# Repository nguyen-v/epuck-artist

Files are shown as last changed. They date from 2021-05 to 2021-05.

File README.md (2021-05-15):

# epuck-artist


An edge processing, 4-color equipped wall plotter. 

Embedded Systems and Robotics semester project at [EPFL](https://www.epfl.ch/) using the e-puck 2 robot from [GCtronic](https://www.gctronic.com/).

## Features
- Reproduction of any subject (100 x 90) in 4 different colors (camera, stepper motor)
- Semi-automatic calibration (TOF sensor, stepper motor)
- Interactive starting position configuration (IR sensors, stepper motor)
## Requirements
### Python 3.x
#### External libraries
  - serial
  - PIL
  - numpy

### VSCode with PlatformIO IDE
#### Libraries
  - NeoSWSerial
  - ServoTimer2
  - Stepper

### Eclipse IDE
#### Libraries
  - [e-puck2_main_processor](https://github.com/e-puck2/e-puck2_main-processor) ([wiki](https://www.gctronic.com/doc/index.php?title=e-puck2_robot_side_development))

### Hardware
| Peripheral | Model |
|---|---|
| Robot | [e-puck2 (GCtronic)](https://www.gctronic.com/e-puck2.php) |
| Board | [Arduino Nano ATMega328](https://store.arduino.cc/arduino-nano) | 
| Bluetooth module | [Velleman HC-05](https://www.velleman.eu/products/view/?id=435518) | 
| Servo motor | [ST55MG](https://amewi.com/AMX-Racing-Micro-Digital-Servo-ST55MG) |
| Stepper motor and driver | [Gear Stepper Motor Driver Pack](https://www.seeedstudio.com/Gear-Stepper-Motor-Driver-Pack-p-3200.html) |

## Demos:
### Live demo
<a href="http://www.youtube.com/watch?feature=player_embedded&v=znKsJ0n5lfQ
" target="_blank">IMAGE ALT TEXT HERE</a>

### Timelapses
#### Colorful concentric circles
<a href="http://www.youtube.com/watch?feature=player_embedded&v=ZIJO9M60r-s
" target="_blank">IMAGE ALT TEXT HERE</a>

#### Cubes
<a href="http://www.youtube.com/watch?feature=player_embedded&v=i3Xt1w0KOP0
" target="_blank">IMAGE ALT TEXT HERE</a>

#### GCtronic logo
<a href="http://www.youtube.com/watch?feature=player_embedded&v=iaR-Tps1SmQ
" target="_blank">IMAGE ALT TEXT HERE</a>

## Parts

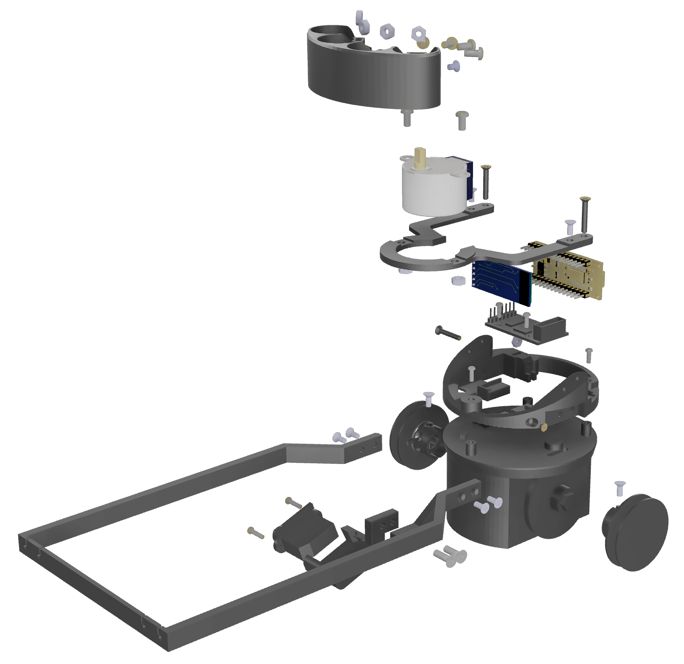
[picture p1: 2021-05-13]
3d_printed_parts/e-puck_exploded_view.png

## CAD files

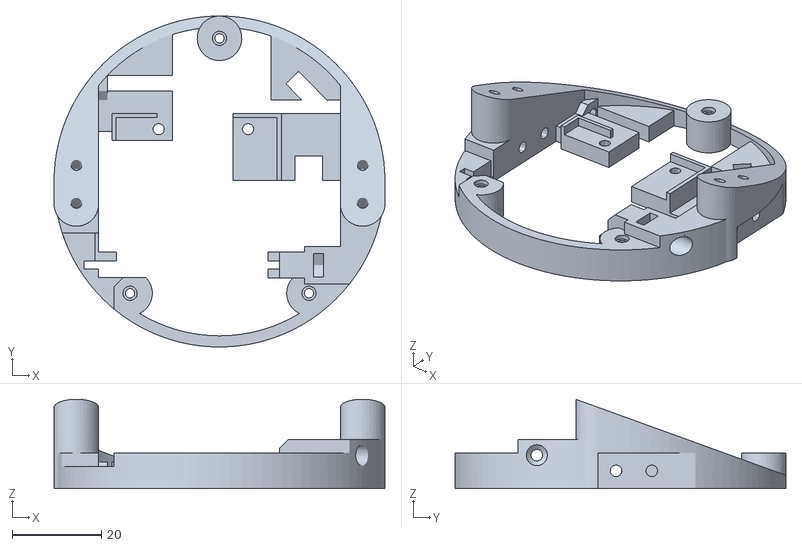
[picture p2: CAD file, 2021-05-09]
3d_printed_parts/MAIN_SUPPORT.stl
74.0 x 74.0 x 20.0

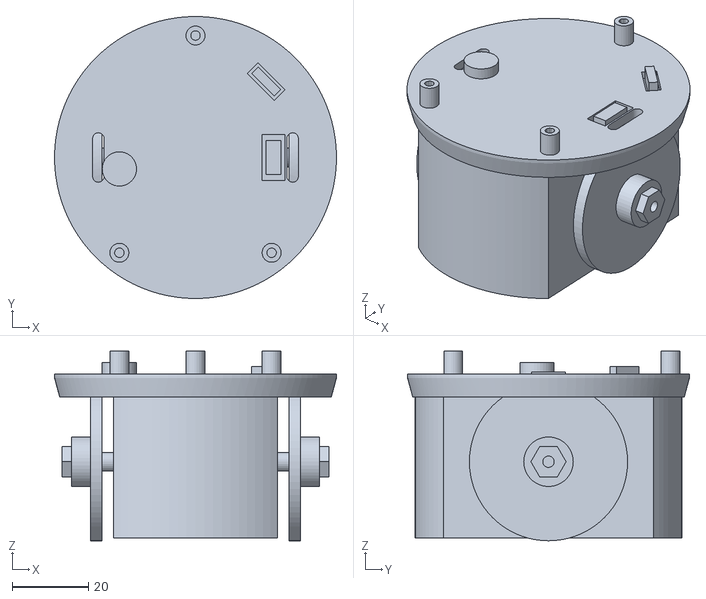
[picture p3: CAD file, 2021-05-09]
misc/EPUCK-2.stl
74.0 x 74.0 x 49.8

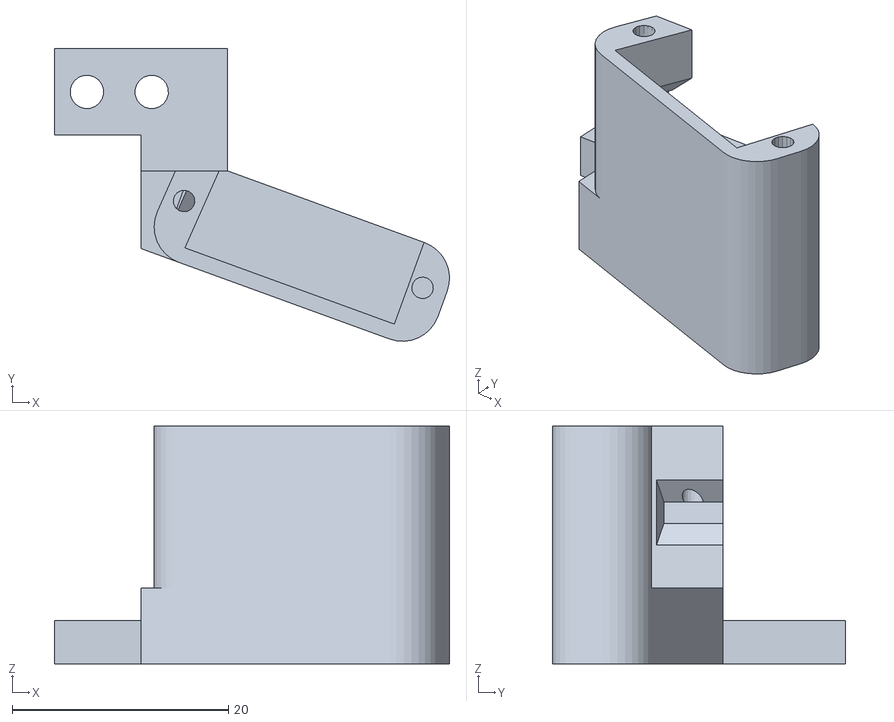
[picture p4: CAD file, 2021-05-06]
3d_printed_parts/SERVO_HOLDER.stl
36.6 x 27.1 x 22.0

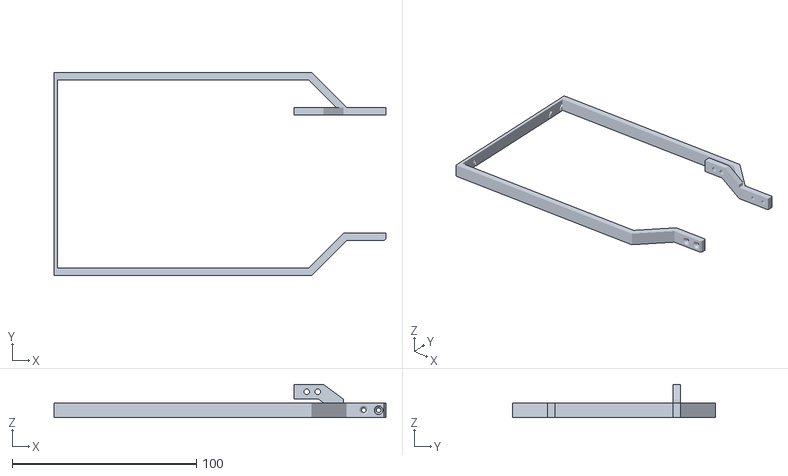
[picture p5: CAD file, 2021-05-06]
3d_printed_parts/THREAD_ALIGNER.stl
180.0 x 110.0 x 18.0

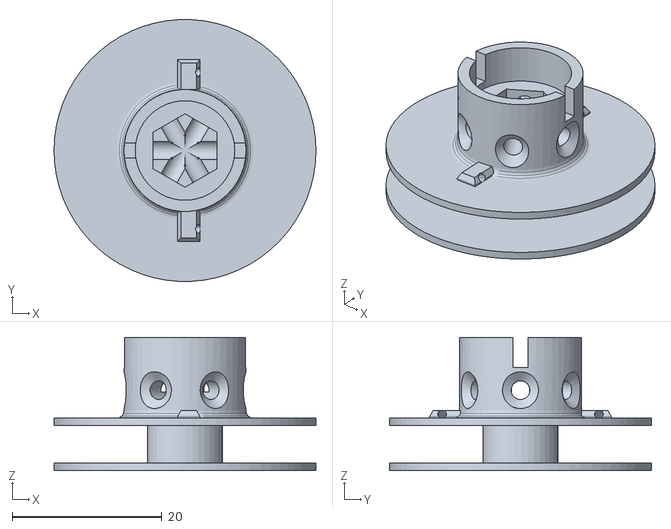
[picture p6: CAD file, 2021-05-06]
3d_printed_parts/WHEEL_PULLEY_D10.stl
35.0 x 35.0 x 17.8

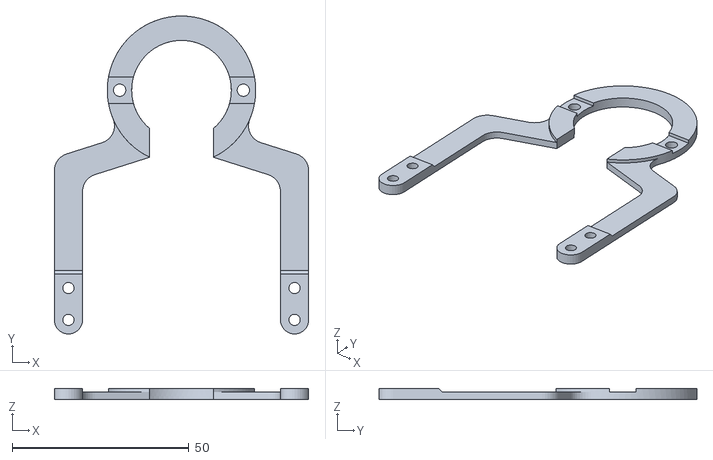
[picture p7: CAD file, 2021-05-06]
3d_printed_parts/STEPPER_SUPPORT.stl
72.0 x 90.0 x 3.00

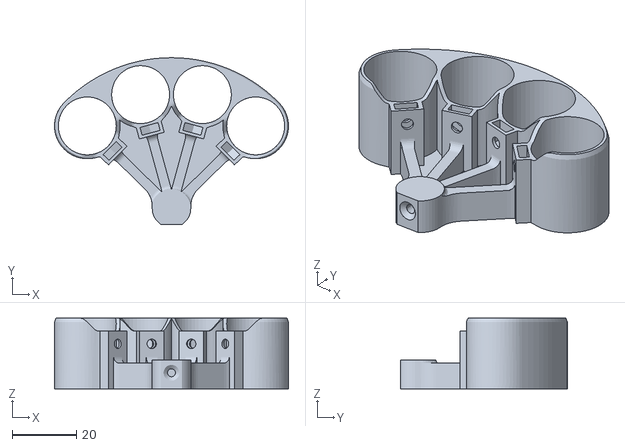
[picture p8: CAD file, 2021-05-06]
3d_printed_parts/PEN_CARRIAGE.stl
72.7 x 51.8 x 22.0

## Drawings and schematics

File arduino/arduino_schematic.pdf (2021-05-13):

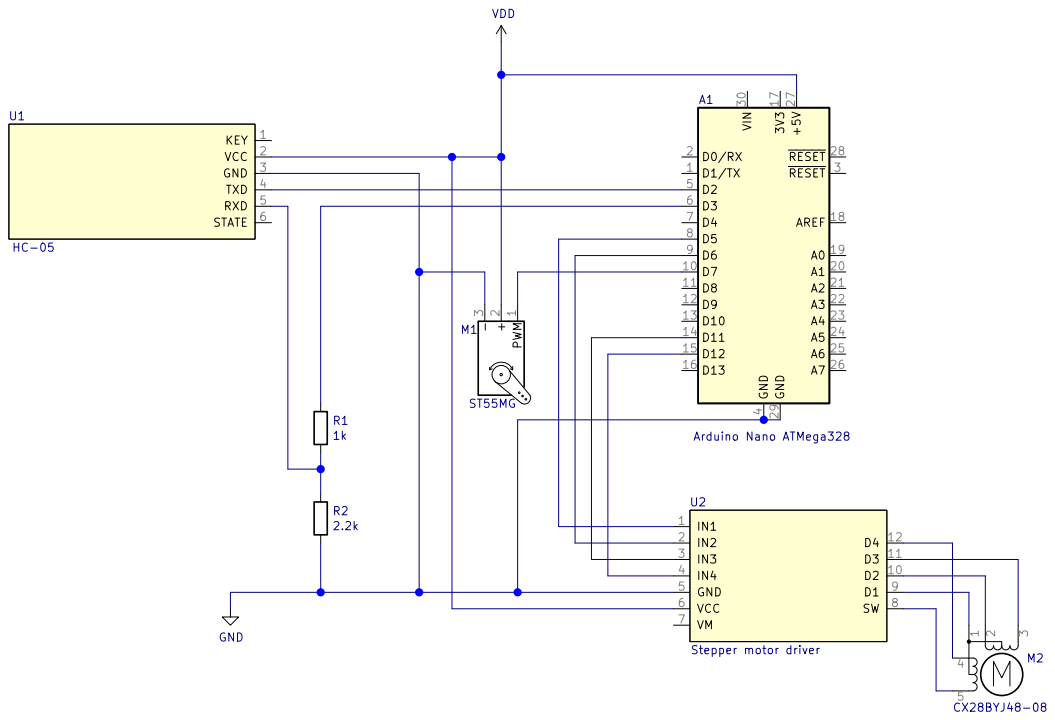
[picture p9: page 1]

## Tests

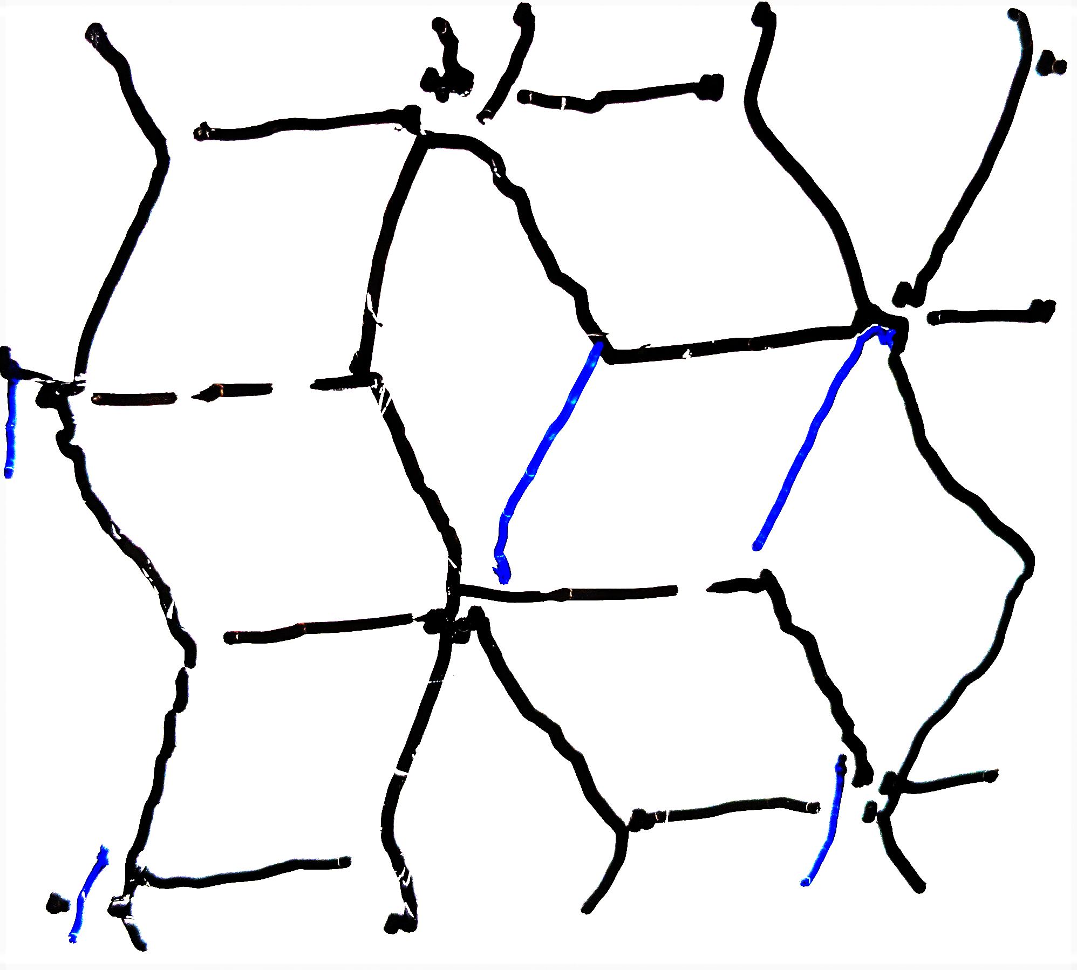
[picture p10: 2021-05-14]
misc/examples/cubes/result_cubes.png

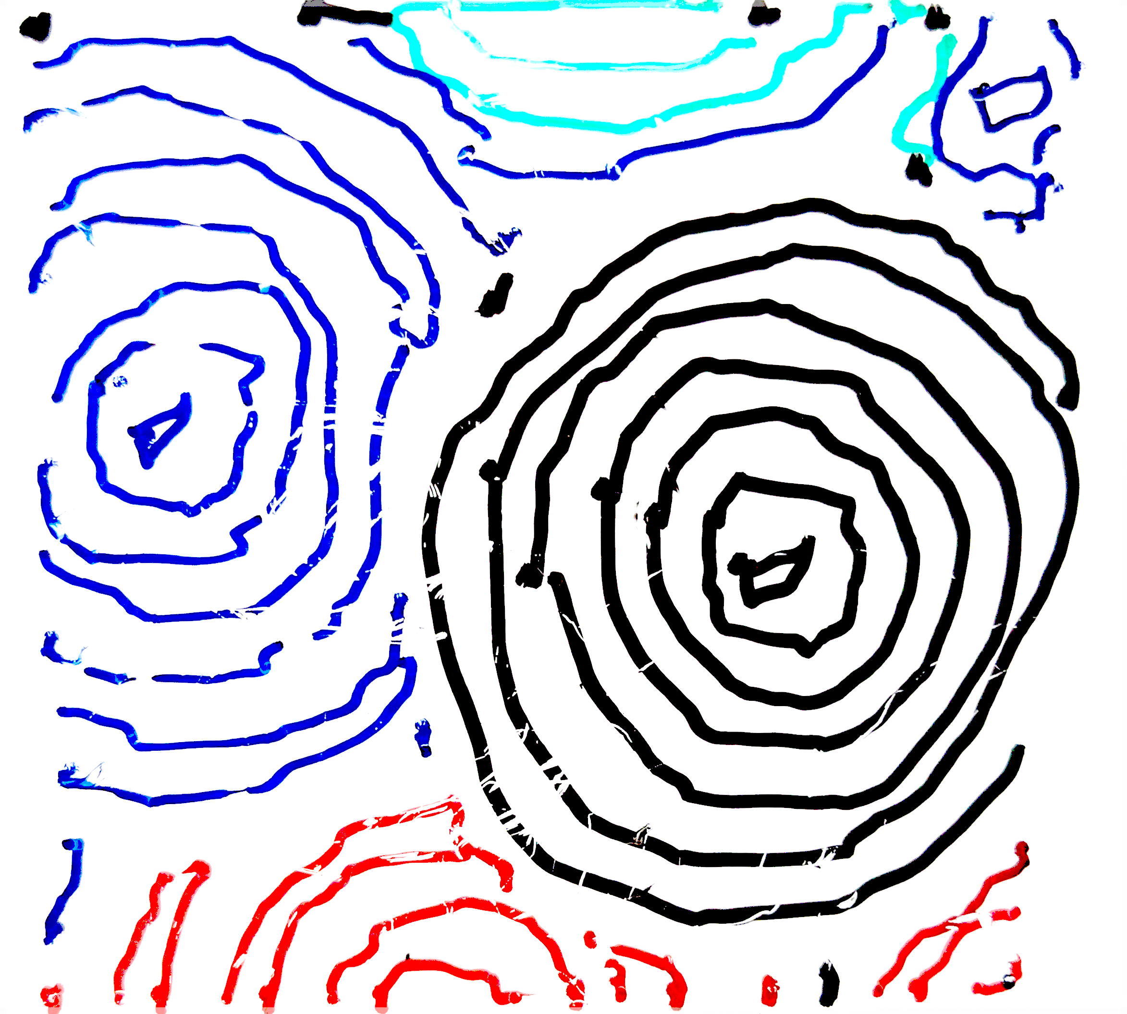
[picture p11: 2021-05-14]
misc/examples/circles/result_circles.png

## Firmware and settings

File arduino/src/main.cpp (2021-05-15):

/**
 * @file    main.cpp
 * @brief   Handles BT communication, servomotor and stepper motor of Arduino.
 *          Very simple program to move the stepper motor to the correct 
 *          position and lift the pens if necessary.
 * 
 * @note    SoftwareSerial.h and Servo.h conflict with each other (timer)
 *          The only compatible libraries tested are NeoSWSerial paired
 *          with ServoTimer2
 */

// Hardware                                                                  

// Board:                 Arduino Nano ATmega328
// Bluetooth module:      Whadda Funkmodul HC-05 Bluetooth
// Servomotor:            Amewi Servo Digital Micro ST55MG 5.5g 
// Stepper motor/driver:  Gear Stepper Motor Driver Pack - Seeed Studio

#include <Arduino.h>

// Libraries
#include <NeoSWSerial.h>
#include <ServoTimer2.h>
#include <Stepper.h>

/*===========================================================================*/
/* Module constants.                                                         */
/*===========================================================================*/

// Messages
#define CONFIMATION_MSG           "Ready"

// Intervals
#define SERVO_STEPPER_INTERVAL    500 // ms

// HC-05 bluetooth module
#define BT_SERIAL_PIN_1           2
#define BT_SERIAL_PIN_2           3
#define BT_BAUD_RATE              9600

// Serial
#define SERIAL_BAUD_RATE          9600

// Servo
#define PIN_SERVO                 10
#define DELTA_PULSE               350

// Stepper
#define PIN_STEPPER_1             5
#define PIN_STEPPER_2             11
#define PIN_STEPPER_3             6
#define PIN_STEPPER_4             12
#define STEPPER_SPEED             5
#define STEPS_PER_REV             2048

// 4 pens are placed on a bit more of a quarter of the full revolution
#define STEPPER_MAX_VALUE         690

// because of weight distribution, epuck is tilted depending on the color chosen
// an offset is added to compensate. The positions are from right to left.
#define STEPPER_OFFSET            30
#define STEPPER_POSITION_0        (0 + STEPPER_OFFSET)
#define STEPPER_POSITION_1        (STEPPER_MAX_VALUE/4 + STEPPER_OFFSET/2)
#define STEPPER_POSITION_2        (STEPPER_MAX_VALUE*2/4 - STEPPER_OFFSET/2)
#define STEPPER_POSITION_3        (STEPPER_MAX_VALUE*3/4 - STEPPER_OFFSET)

#define DEFAULT_POSITION          STEPPER_POSITION_0

/*===========================================================================*/
/* Module data structures and types.                                         */
/*===========================================================================*/
enum Color {white, black, red, green, blue};

/*===========================================================================*/
/* Module local variables.                                                   */
/*===========================================================================*/

static NeoSWSerial BTserial(BT_SERIAL_PIN_1, BT_SERIAL_PIN_2);
static ServoTimer2 servo;
static Stepper stepper = Stepper(STEPS_PER_REV, PIN_STEPPER_1, PIN_STEPPER_2, 
                                 PIN_STEPPER_3, PIN_STEPPER_4);
static int16_t stepper_position = DEFAULT_POSITION;


/*===========================================================================*/
/* Module local functions.                                                   */
/*===========================================================================*/

/**
 * @brief             moves stepper motor and servo motor to change colors
 * @param[in]   col   a valid color (enum Color)
 * @return            none
 */
static void change_color(Color col)
{
	// lift servo
	servo.write(DEFAULT_PULSE_WIDTH+DELTA_PULSE);
	delay(SERVO_STEPPER_INTERVAL);
	int16_t goal_step = 0;
	switch (col) {
		case white:
			return; // if white is requested, just lift the pens
			break;
		case black:
			goal_step = STEPPER_POSITION_0;
			break;
		case red:
			goal_step = STEPPER_POSITION_1;
			break;
		case green:
			goal_step = STEPPER_POSITION_2;
			break;
		case blue:
			goal_step = STEPPER_POSITION_3;
			break;
	}

	int16_t delta_step = goal_step - stepper_position;
	stepper.step(delta_step);
	delay(SERVO_STEPPER_INTERVAL);
	stepper_position = goal_step;
	// lower servo
	servo.write(DEFAULT_PULSE_WIDTH);
}

/**
 * @brief             resets motors to their standby state.
 * @return            none
 */
static void reset_motors()
{
	servo.write(DEFAULT_PULSE_WIDTH+DELTA_PULSE);
	delay(SERVO_STEPPER_INTERVAL);
	int16_t goal_step = DEFAULT_POSITION;
	int16_t delta_step = goal_step - stepper_position;
	stepper.step(delta_step);
	stepper_position = goal_step;
}

/*===========================================================================*/
/* Module functions.                                                         */
/*===========================================================================*/

void setup() 
{
	servo.attach(PIN_SERVO);
	stepper.setSpeed(STEPPER_SPEED);

	Serial.begin(SERIAL_BAUD_RATE);
	BTserial.begin(BT_BAUD_RATE);

	delay(SERVO_STEPPER_INTERVAL);
	servo.write(DEFAULT_PULSE_WIDTH+DELTA_PULSE);
}

void loop() 
{
	if (BTserial.available()) {
		char cmd = BTserial.read();
		switch (cmd) {
			case 'W':
				change_color(white);
				break;
			case 'D': // dark
				change_color(black);
				break;
			case 'R':
				change_color(red);
				break;
			case 'G':
				change_color(green);
				break;
			case 'B':
				change_color(blue);
				break;
			case 'X':
				reset_motors();
				break;
		}
	BTserial.println(CONFIMATION_MSG);
	}
}

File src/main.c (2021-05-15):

/**
 * @file    main.c
 * @brief   Main file. Handles interactions between modules.
 */

// ChibiOS headers

#include "ch.h"
#include "hal.h"
#include "memory_protection.h"
#include "chprintf.h"
#include <usbcfg.h>
#include <motors.h>

// e-puck 2 main processor headers

#include <camera/po8030.h>
#include "camera/dcmi_camera.h"


// Module headers

#include <main.h>
#include <mod_sensors.h>
#include <mod_draw.h>
#include <mod_communication.h>
#include <mod_img_processing.h>
#include <mod_calibration.h>
#include <mod_data.h>
#include <mod_state.h>

/*===========================================================================*/
/* Module local functions.                                                   */
/*===========================================================================*/

/**
 * @brief             Initalizes all modules.
 */
static void init_all(void)
{
	halInit();
	chSysInit();
	mpu_init();
//	usb_start(); // uncomment if using chprintf on SDU1
	dcmi_start();
	po8030_start();
	com_serial_start();
	mod_img_processing_init();
	motors_init();
	sensors_init();
}

/*===========================================================================*/
/* Main function.                                                   		 */
/*===========================================================================*/


int main(void)
{
	init_all();
	draw_set_init_length(DEFAULT_HEIGHT_CM);
	create_thd_process_cmd();
	while(1) {
		chThdSleepMilliseconds(100);
    }
}

#define STACK_CHK_GUARD 0xe2dee396
uintptr_t __stack_chk_guard = STACK_CHK_GUARD;

void __stack_chk_fail(void)
{
    chSysHalt("Stack smashing detected");
}

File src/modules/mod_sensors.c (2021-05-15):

/**
 * @file    mod_sensors.c
 * @brief   Module for managing sensors
 */

// C standard header files

#include <stdio.h>
#include <stdlib.h>
#include <math.h>

// ChibiOS headers

#include "ch.h"
#include "hal.h"
#include "memory_protection.h"
#include "msgbus/messagebus.h"
#include "chprintf.h"
#include <usbcfg.h>

// e-puck 2 main processor headers

#include "sensors/VL53L0X/VL53L0X.h"
#include "sensors/proximity.h"

// Module headers

#include <mod_sensors.h>
#include <mod_communication.h>
#include <mod_calibration.h>
#include <mod_data.h>
#include <mod_state.h>

/*===========================================================================*/
/* Module constants.                                                         */
/*===========================================================================*/

#define BLINK_PERIOD       200
#define BLINK_MAX_COUNT    3
#define TOF_PERIOD         100

#define OBSERVED_NOISE_COVARIANCE 6.5f

/*===========================================================================*/
/* Bus related declarations.                                                 */
/*===========================================================================*/

messagebus_t bus;
MUTEX_DECL(bus_lock);
CONDVAR_DECL(bus_condvar);

/*===========================================================================*/
/* Module local variables.                                                   */
/*===========================================================================*/

static uint16_t dist_mm_kalman = 0;

/*===========================================================================*/
/* Module thread pointers.                                                   */
/*===========================================================================*/

static thread_t* ptr_tof_kalman;

/*===========================================================================*/
/* Module local functions.                                                   */
/*===========================================================================*/


/**
 * @brief               1D Kalman filter
 *
 * @return              filtered value
 * @note                Kalman filter is defined in VL53L0X.c because we want
 *                      it to be ready (i.e. running) alongside the thread
 *                      defined in the same file (because values need to be
 *                      stable when accessed).
 *                      sources: https://www.youtube.com/watch?v=ruB917YmtgE
 *                               https://en.wikipedia.org/wiki/Kalman_filter
 */
static uint16_t kalman1d(uint16_t U)
{
	static const float R = OBSERVED_NOISE_COVARIANCE;
	static const float H = 1.00;       // observation model
	static float Q = 1.0;              // initial estimated covariance
	static float P = 0;                // initial error covariance
	static uint16_t U_hat = 0;         // initial predicted state
	static float K = 0;

	K = P*H/(H*P*H+R);                 // calculate Kalman gain
	U_hat = U_hat + K*(U-H*U_hat);     // updated state estimate
	P = (1-K*H)*P +Q;                  // updated estimate covariance
	return U_hat;
}



/*===========================================================================*/
/* Module threads.                                                           */
/*===========================================================================*/

/**
 * @brief   Thread for applying Kalman filter to TOF measurements.
 */
static THD_WORKING_AREA(wa_tof_kalman, 256);
static THD_FUNCTION(thd_tof_kalman, arg)
{
	chRegSetThreadName(__FUNCTION__);
	(void)arg;

	while (1) {
		dist_mm_kalman = kalman1d(VL53L0X_get_dist_mm());
//		chprintf((BaseSequentialStream *)&SDU1, "dist %d", dist_mm_kalman);
		chThdSleepMilliseconds(TOF_PERIOD);
	}
}

/**
 * @brief            Create TOF measurement thread with Kalman filter
 * @return           none
 */
static void tof_kalman_create_thd(void)
{
	ptr_tof_kalman = chThdCreateStatic(wa_tof_kalman, sizeof(wa_tof_kalman),
	                                   NORMALPRIO, thd_tof_kalman, NULL);
}

/*===========================================================================*/
/* Module exported functions.                                                */
/*===========================================================================*/

void sensors_init(void)
{
	messagebus_init(&bus, &bus_lock, &bus_condvar);
	proximity_start();
	VL53L0X_start();
	tof_kalman_create_thd();
	calibrate_ir();
}


uint16_t sensors_tof_kalman(void)
{
	return dist_mm_kalman;
}


uint16_t sensors_tof_wait(uint16_t distance_min, uint16_t distance_max,
                          uint8_t distance_threshold, uint16_t time_ms)
{
	uint8_t state = 0;
	uint16_t time_interval = time_ms/4;
	uint16_t current_dist = 0;
	uint16_t prev_dist = current_dist;

	while (state != 4 && cal_get_state() == true) {
		current_dist = dist_mm_kalman;
		if (state == 0) {
			// turn off the leds
			palSetPad(GPIOD, GPIOD_LED1);
			palSetPad(GPIOD, GPIOD_LED3);
			palSetPad(GPIOD, GPIOD_LED5);
			palSetPad(GPIOD, GPIOD_LED7);
		}

		if (state == 0 && distance_min <= current_dist && distance_max >= current_dist) {
			state = 1;
			prev_dist = current_dist;
			palClearPad(GPIOD, GPIOD_LED1);
			chThdSleepMilliseconds(time_interval);
			current_dist = dist_mm_kalman;
		} else {
			state = 0;
		}

		if (state == 1 && abs((int16_t)current_dist - (int16_t)prev_dist)
		                                          <= distance_threshold) {
			state = 2;
			prev_dist = current_dist;
			palClearPad(GPIOD, GPIOD_LED3);
			chThdSleepMilliseconds(time_interval);
			current_dist = dist_mm_kalman;
		} else {
			state = 0;
		}

		if (state == 2 && abs((int16_t)current_dist - (int16_t)prev_dist)
		                                          <= distance_threshold) {
			state = 3;
			prev_dist = current_dist;
			palClearPad(GPIOD, GPIOD_LED5);
			chThdSleepMilliseconds(time_interval);
			current_dist = dist_mm_kalman;
		} else {
			state = 0;
		}

		if (state == 3 && abs((int16_t)current_dist - (int16_t)prev_dist)
		                                          <= distance_threshold) {
			state = 4;
			prev_dist = current_dist;
			palClearPad(GPIOD, GPIOD_LED7);
			chThdSleepMilliseconds(time_interval);
		} else {
			state = 0;
		}
		chThdSleepMilliseconds(TOF_PERIOD);
	}

	// blink leds on success
	for (uint8_t i = 0; i < BLINK_MAX_COUNT; ++ i) {

		palClearPad(GPIOD, GPIOD_LED1);
		palClearPad(GPIOD, GPIOD_LED3);
		palClearPad(GPIOD, GPIOD_LED5);
		palClearPad(GPIOD, GPIOD_LED7);

		chThdSleepMilliseconds(BLINK_PERIOD);

		palSetPad(GPIOD, GPIOD_LED1);
		palSetPad(GPIOD, GPIOD_LED3);
		palSetPad(GPIOD, GPIOD_LED5);
		palSetPad(GPIOD, GPIOD_LED7);

		chThdSleepMilliseconds(BLINK_PERIOD);
	}
	return current_dist;
}

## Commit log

2021-04-02 Added thread for processing commands
2021-04-02 removed thread
2021-04-06 Grayscale conversion, Gaussion filter are implemented. Sobel filter still in progress
2021-04-06 Revert "Added edge smoothing/tracking and double threshold."
    This reverts commit cb1635581757fb676e142e09e363651cf50c225c.
    [epuck-communication.py, main.c]
2021-04-08 Disable stepper motor power saving
2021-04-19 Contours to motor path conversion module completed.
2021-04-22 Added sensor module
2021-04-22 Added draw thread functions
2021-04-22 Added kalman filter to TOF sensor
2021-04-22 Added calibration module
2021-04-24 Added semi-automatic calibration thread
2021-04-24 Modified thread termination conditions
2021-04-29 Performance improvements and filters
2021-05-03 Added threads to read BT serials from arduino and epuck, and handles communication between the 2
2021-05-06 Added 3d printed parts (stl files)
    [MAIN_SUPPORT.stl, PEN_CARRIAGE.stl, SERVO_HOLDER.stl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]
2021-05-06 Fixed orientation on plate
    [SERVO_HOLDER.stl, THREAD_ALIGNER.stl, WHEEL_PULLEY_D10.stl]
2021-05-06 Added comments to kalman filter implementation
2021-05-06 Added semaphore to signal color changing for calibration
2021-05-07 FIxed handling of thread suspend and semaphore for color change Added manual home point definition using IR sensors
    [mod_calibration.c]
2021-05-07 Replaced thread pause with wait on semaphore on color change to avoid conflict with manual pause
    [mod_draw.c]
2021-05-07 Added IR calibration
2021-05-07 Added arduino related files
2021-05-09 Modeled epuck-2 for exploded view
    [EPUCK-2.stl]
2021-05-09 New version
    [MAIN_SUPPORT.stl]
2021-05-11 Bugfixes for thread suspend/resume
    [mod_calibration.c, mod_draw.c]
2021-05-12 replaced sqrt with sqrtf to avoid cast
    [mod_draw.c]
2021-05-13 Added electrical schematic
2021-05-14 Moved kalman filter to sensors.c
2021-05-14 Changed thread priority and fixed thread suspend during calibration
    [mod_calibration.c]
